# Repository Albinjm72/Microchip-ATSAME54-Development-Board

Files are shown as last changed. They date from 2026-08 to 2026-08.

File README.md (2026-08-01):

<div align="center">

# ATSAME54N20A-AU Development Board

**A custom-designed development board built around the Microchip ATSAME54N20A-AU (ARM Cortex-M4F)**

Designed end-to-end in KiCad — schematic, routing, and silkscreen.

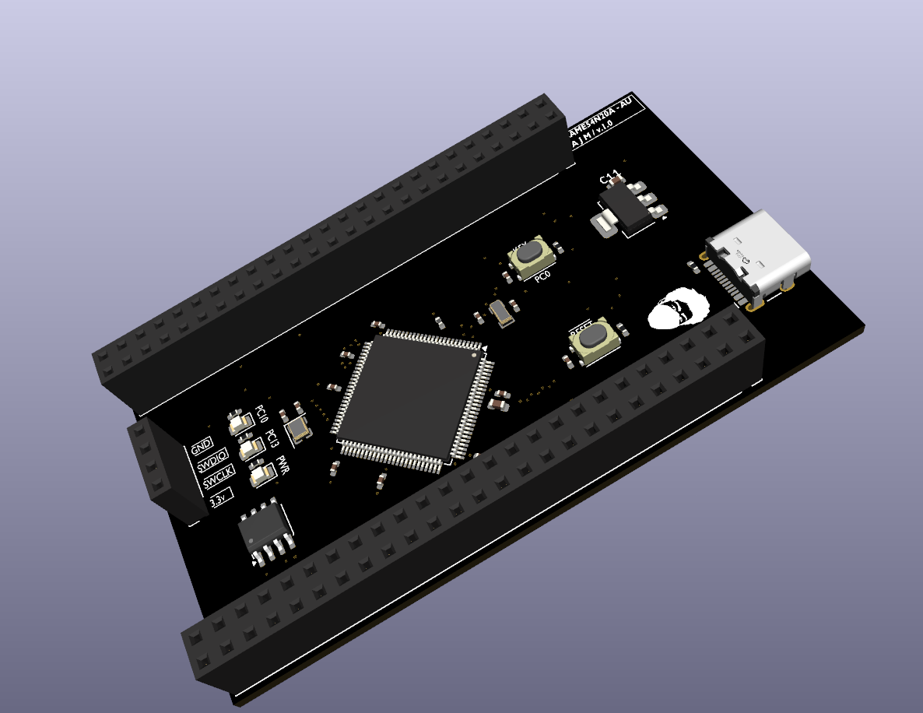
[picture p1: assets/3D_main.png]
Board Render


</div>

---

## Overview

This is a fully custom development board designed from a bare microcontroller datasheet up — power architecture, signal routing, and silkscreen branding all done by hand in KiCad, not adapted from a reference design.

## Features

| Feature | Detail |
|---|---|
| **MCU** | Microchip ATSAME54N20A-AU — ARM Cortex-M4F, 120MHz, 1MB flash, 100-pin TQFP |
| **USB** | USB Type-C connector (power + native USB) |
| **CAN** | Onboard CAN controller/transceiver for real bus communication |
| **Storage** | microSD card slot (SDHC) + external QSPI flash |
| **Debug** | SWD programming/debug header |
| **Indicators** | 1x power LED, 2x user-controllable LEDs |
| **I/O** | Dual 2-row GPIO headers (one on each side) — breadboard-compatible pitch |

## Board layout

- **Left and right edges:** two rows of breakout headers on each side, broken out to standard 2.54mm pitch for direct breadboard use
- **Top section:** power, USB-C, SD card slot, SWD header
- **Center:** ATSAME54N20A-AU (TQFP-100)

## Getting started

1. Clone this repository
2. Open `ATSAME54N20A-AU.kicad_pro` in **KiCad 10** or later
3. Manufacturing-ready files are already generated under `gerber_to_order/` if you just want to order the board as-is

## Programming

Program and debug via the onboard **SWD header** using any ARM-compatible probe (ST-Link, J-Link, Atmel-ICE, or similar), through OpenOCD/GDB or MPLAB X.

## Bill of Materials

Full BOM with reference designators, values, and footprints is in `production/bom.csv`.

## Revision history

See [CHANGELOG.md](CHANGELOG.md) for what changed between board revisions.

## License

Licensed under [CERN-OHL-S v2](LICENSE).

## Status

🔧 **Active development** — first hardware revision fabricated, pending assembly and bring-up testing.

---

<div align="center">
<sub>Built with KiCad · Designed by Albin Jose Mathew</sub>
</div>

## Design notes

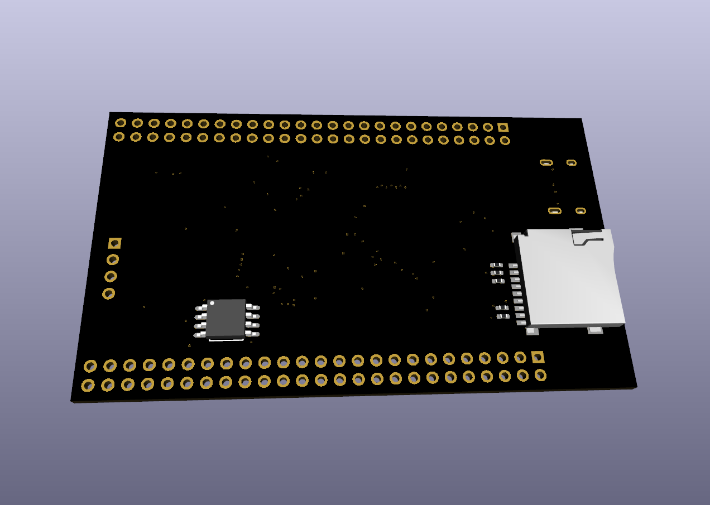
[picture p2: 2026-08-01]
assets/3D_Bottom.png

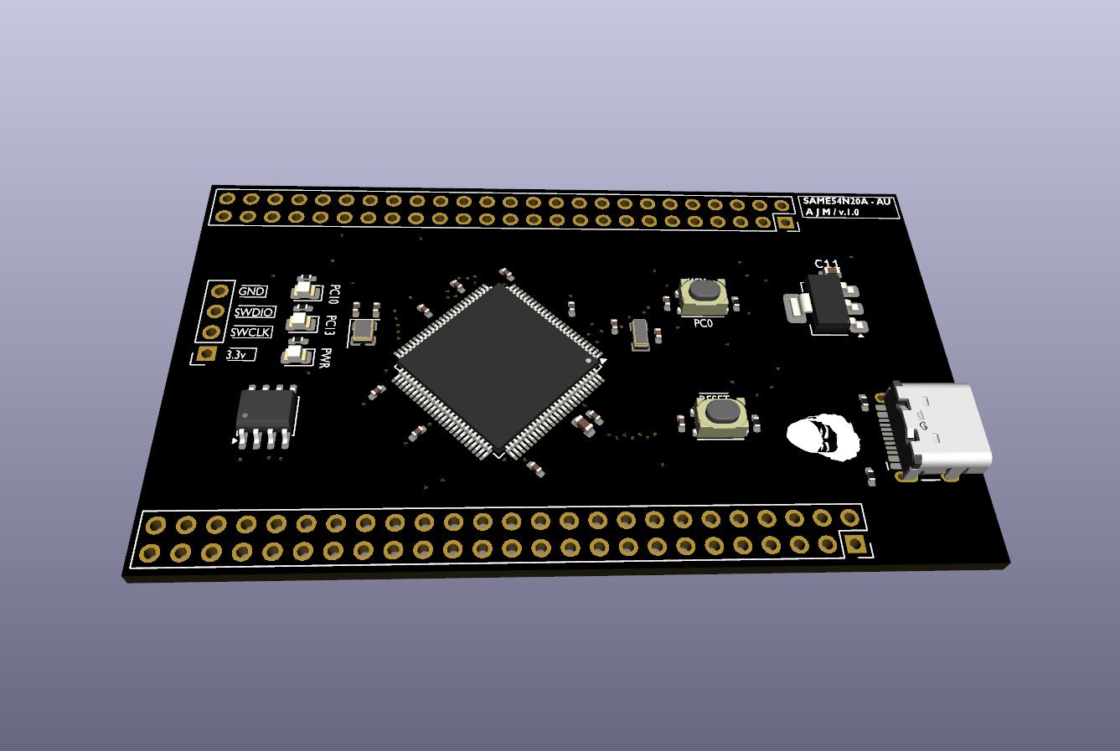
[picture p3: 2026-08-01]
assets/3D_Top_2.png

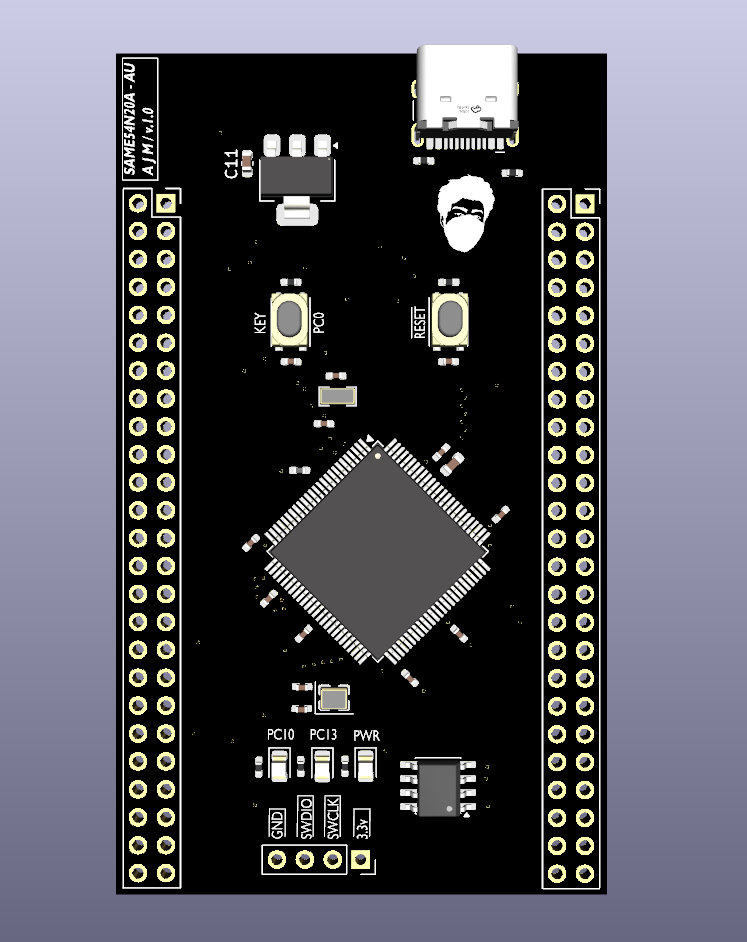
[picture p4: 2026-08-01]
assets/3D_Top_1.png

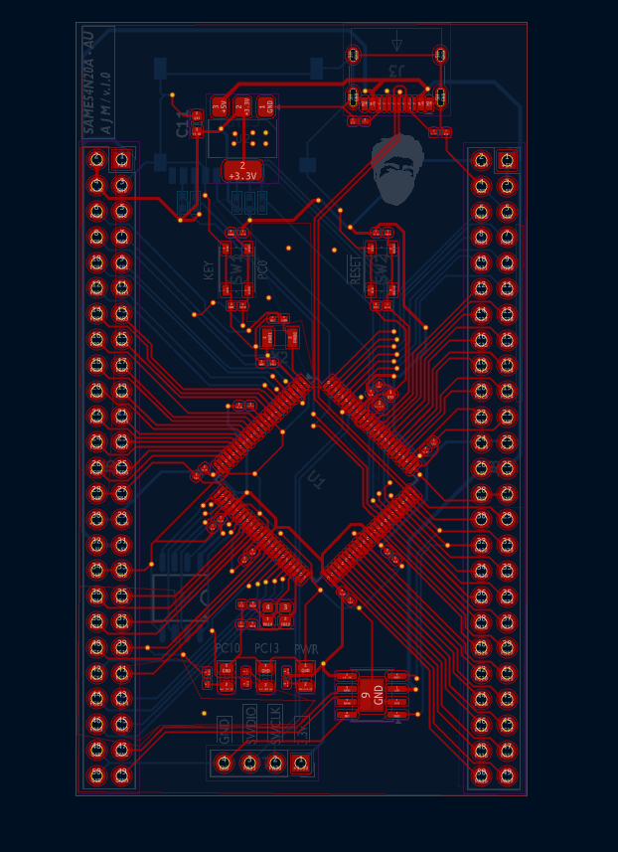
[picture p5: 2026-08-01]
assets/Layout_Top.png

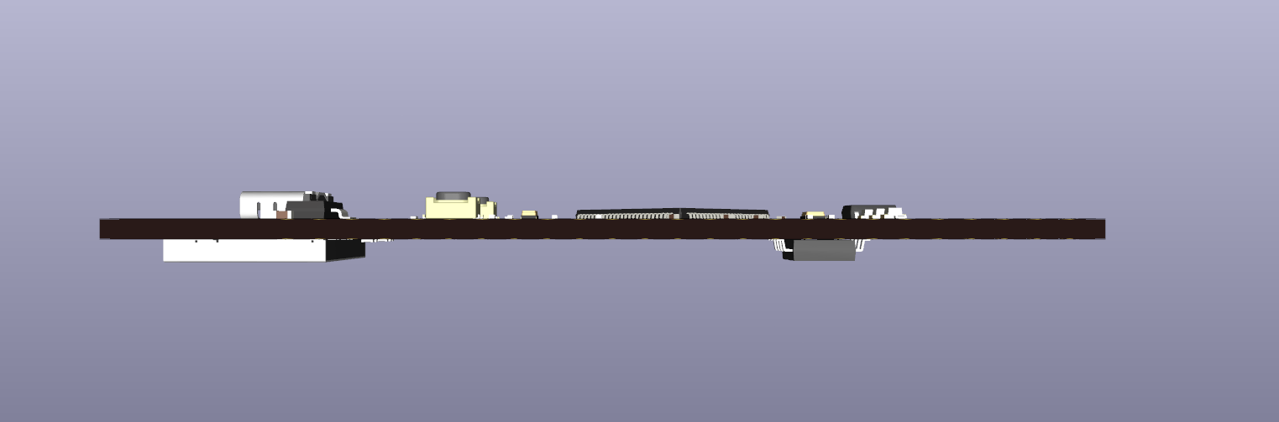
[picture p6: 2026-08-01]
assets/3D_Side_2.png

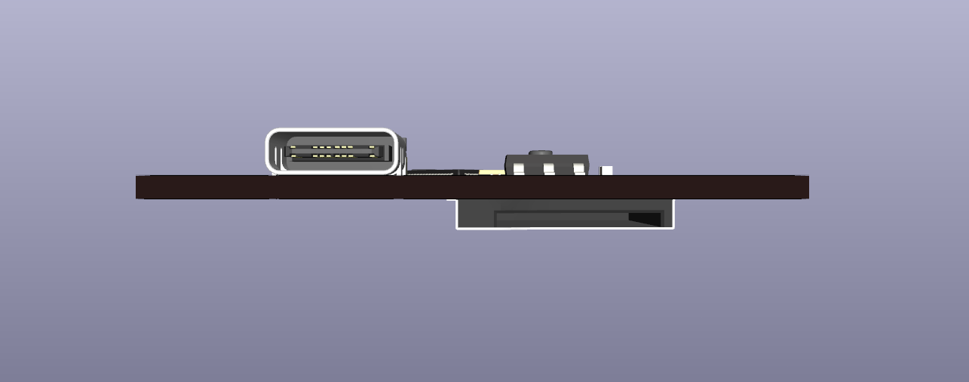
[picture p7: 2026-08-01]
assets/3D_Side_1.png

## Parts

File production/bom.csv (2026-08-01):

Designator | Footprint | Quantity | Value | LCSC Part #
C1, C2, C3, C4, C5, C6, C7, C8, C9 | 0402 | 9 | 100nF
C10 | 0603 | 1 | 1uF
C11 | 0603 | 1 | 10uF
C12, C13 | 0402 | 2 | 12pF
C14, C15 | 0402 | 2 | 15pF
CARD1 | TF-SMD_THD2528-11SD-GF | 1 | THD2528-11SD-GF | C283232
D1 | 0805 | 1 | 0805 GREEN
D2 | 0805 | 1 | 0805 RED
D3 | 0805 | 1 | 0805 ORANGE
FB1 | 0402 | 1 | 600ohm@100MHz
J3 | USB_C_Receptacle_HCTL_HC-TYPE-C-16P-01A | 1 | USB_C_Receptacle_USB2.0_16P
J6, J8 | PinSocket_2x25_P2.54mm_Vertical | 2 | Conn_01x50_MountingPin
J7 | PinSocket_1x04_P2.54mm_Vertical | 1 | Conn_01x04_Pin
R1, R10, R11, R12, R2, R5, R6, R8, R9 | 0402 | 9 | 10k
R3, R4, R7 | 0402 | 3 | 330
SW1, SW2 | SW_Push_1P1T_NO_Vertical_Wuerth_434133025816 | 2 | SW_Push
U1 | TQFP-100_14x14mm_P0.5mm | 1 | ATSAME54N20A-AU
U2 | SOT-223-3_TabPin2 | 1 | TPS7A0533PDBZ
U3 | SOIJ-8_L5.3-W5.3-P1.27-LS7.9-BL | 1 | SST26VF064Bxx-xxxx-MF | C638561
U4 | SOIC-8-1EP_3.9x4.9mm_P1.27mm_EP2.41x3.3mm | 1 | MCP2542FDxMF
Y1 | Crystal_SMD_2520-4Pin_2.5x2.0mm | 1 | Crystal
Y2 | Crystal_SMD_3215-2Pin_3.2x1.5mm | 1 | 32.768kHz

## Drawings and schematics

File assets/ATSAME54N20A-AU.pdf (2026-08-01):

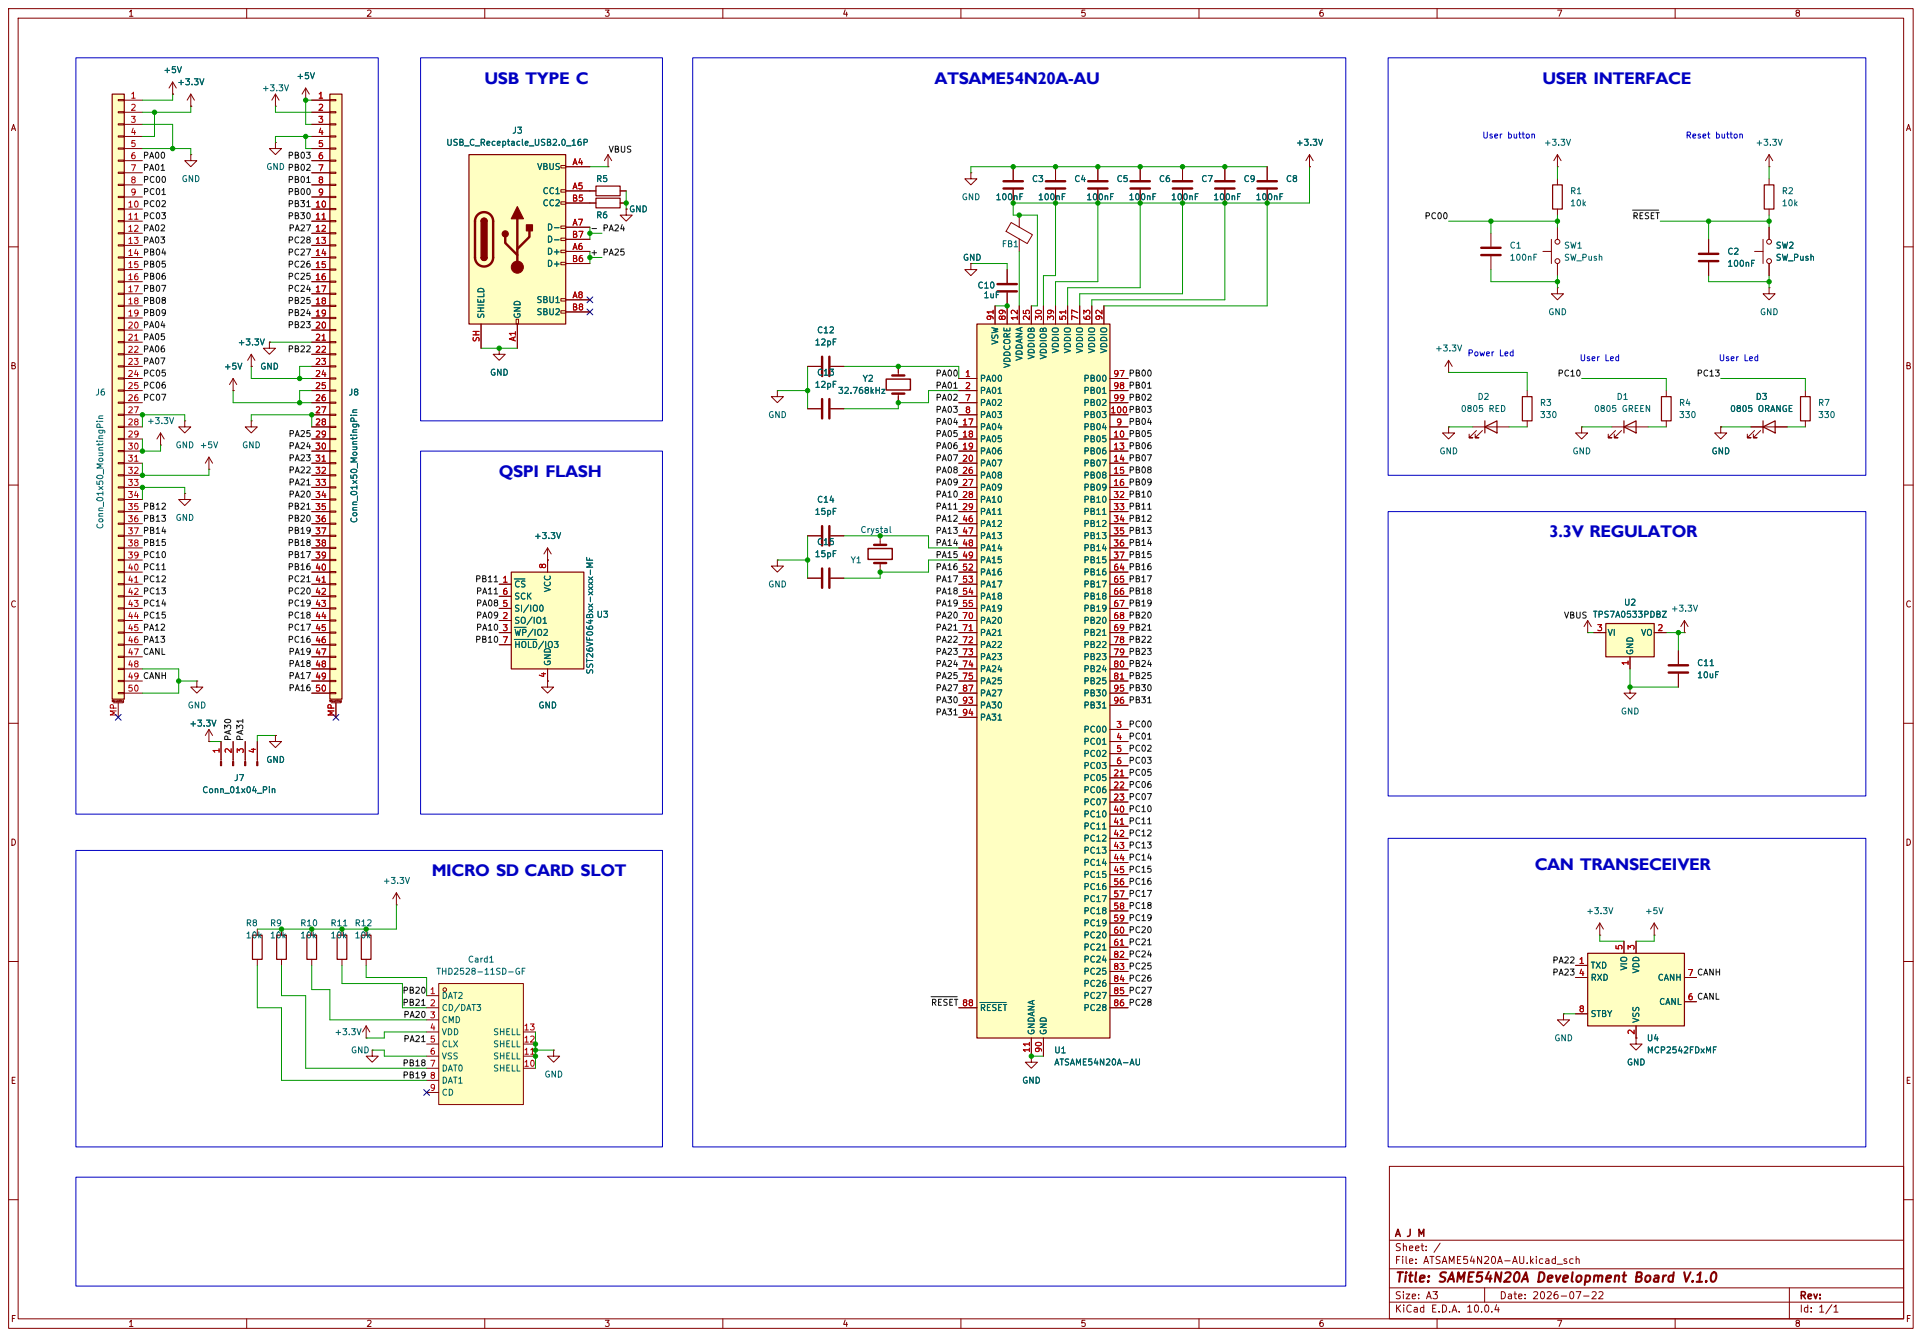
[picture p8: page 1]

User button USB TYPE C

User Led USER INTERFACE
0805 ORANGER2

PB05 PB01 PB02 PB04 MICRO SD CARD SLOT

SHELL 10 SHELL 11 SHELL 12 SHELL 13 Card1

File: ATSAME54N20A-AU.kicad_sch Sheet: /
Id: 1/1 Title: SAME54N20A Development Board V.1.0

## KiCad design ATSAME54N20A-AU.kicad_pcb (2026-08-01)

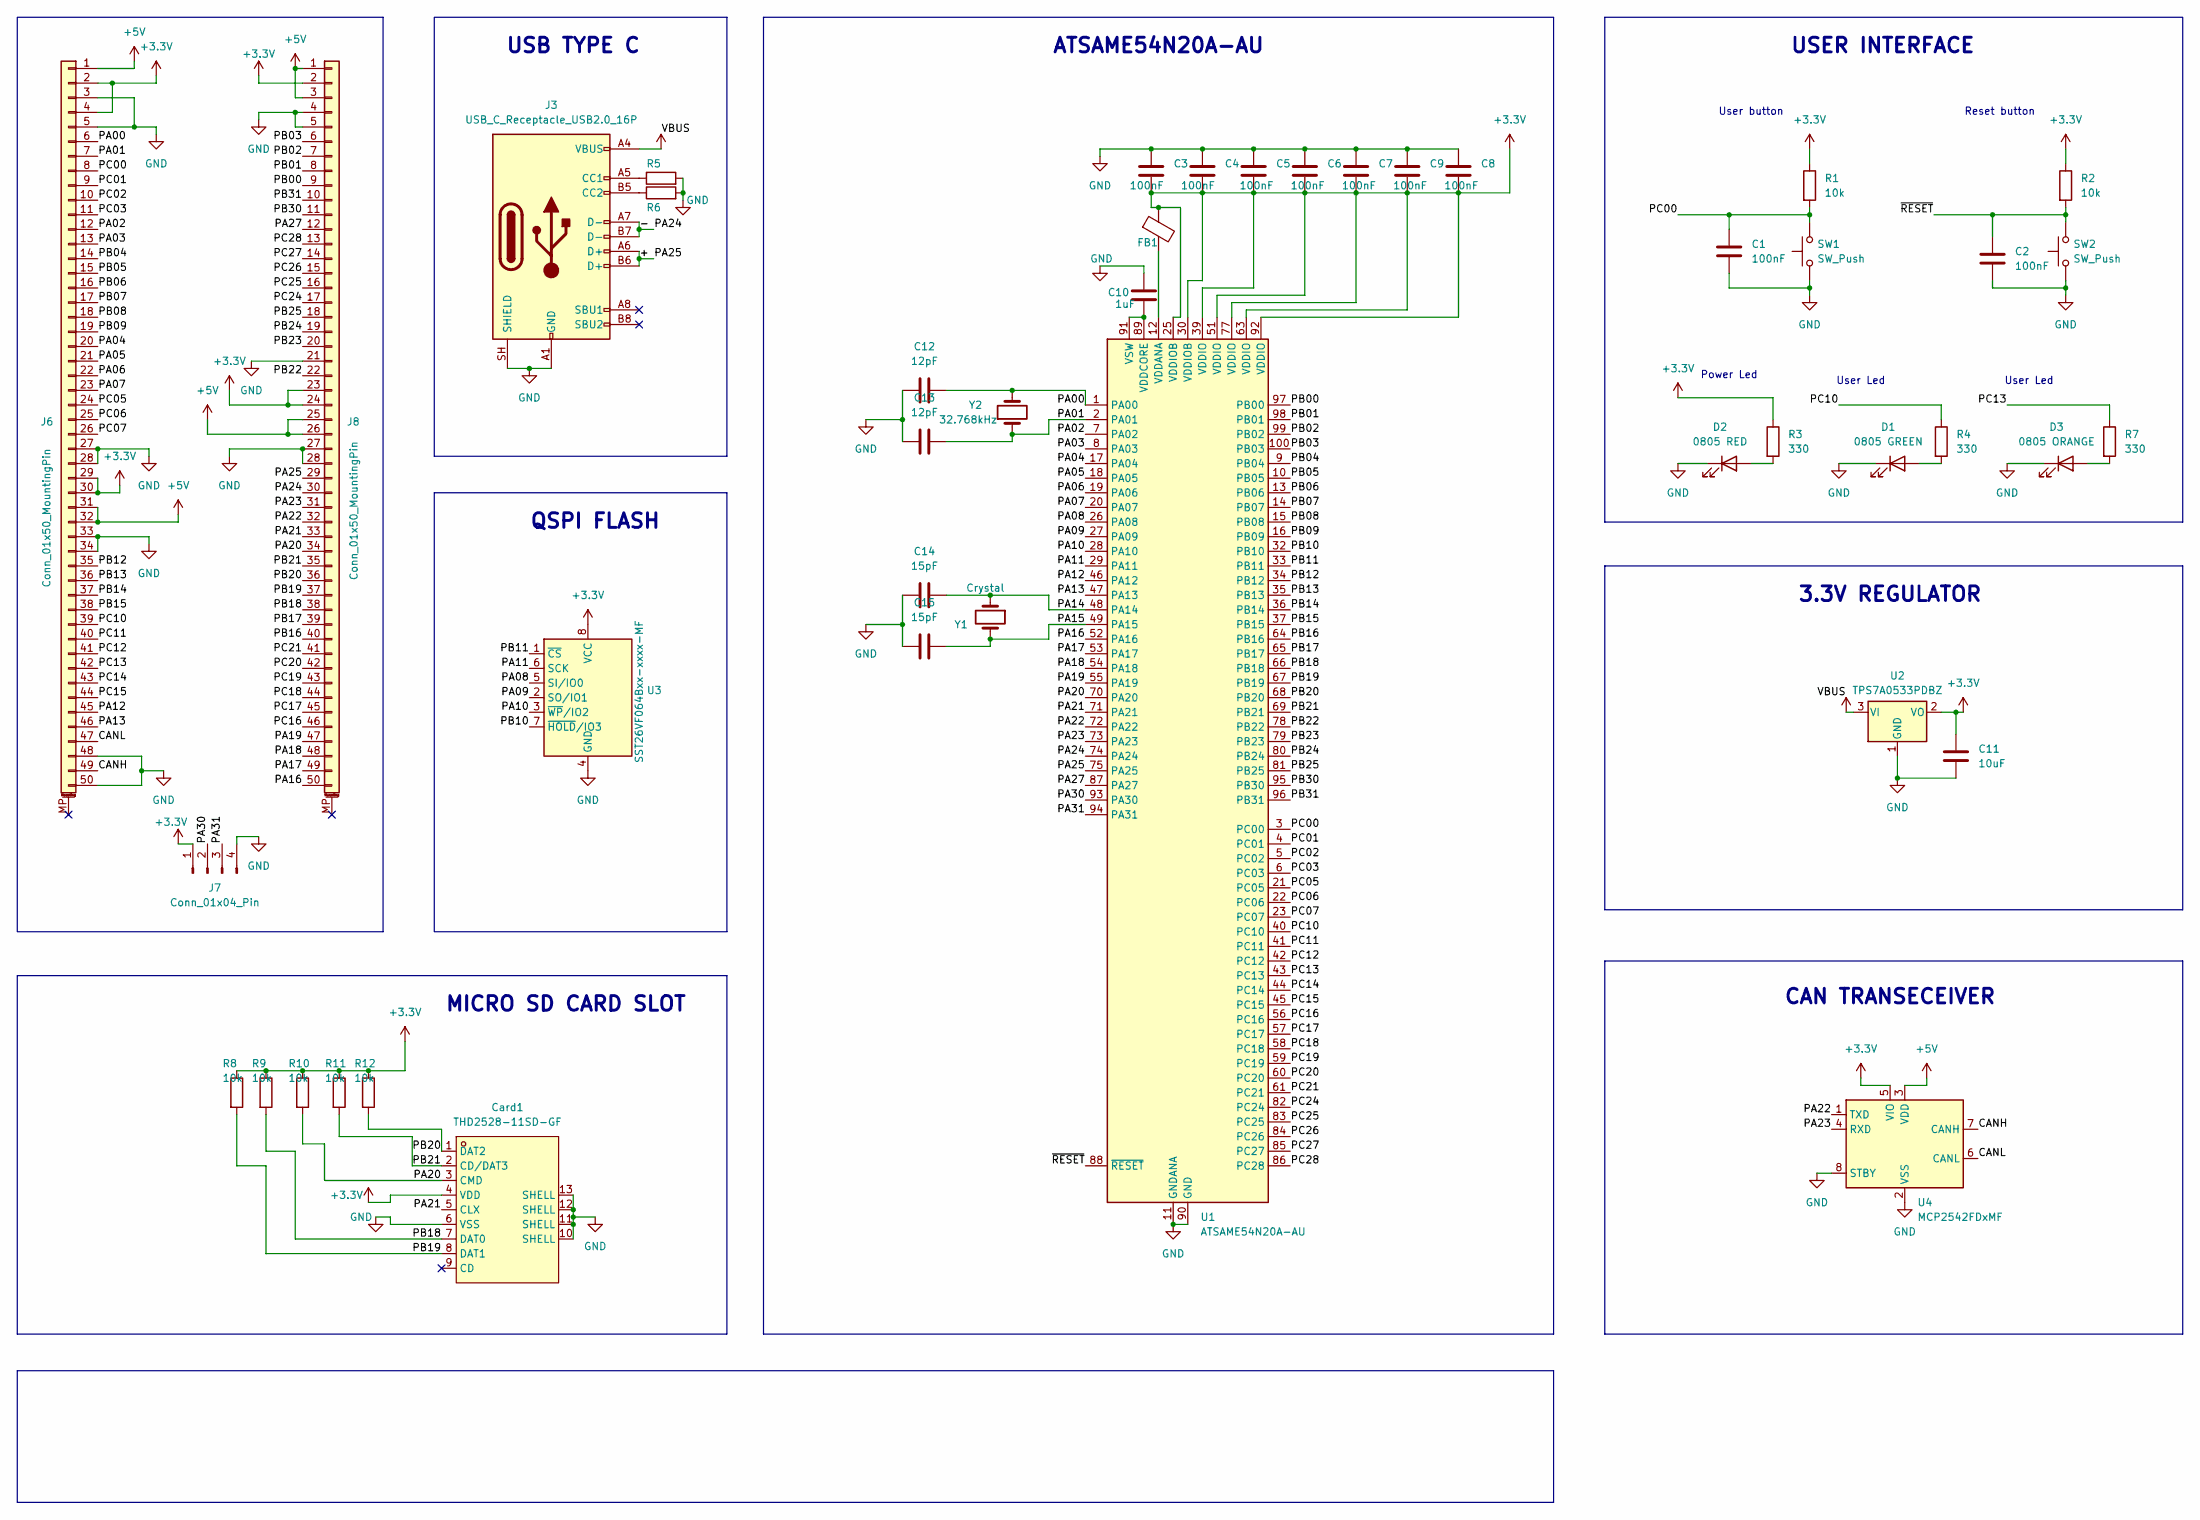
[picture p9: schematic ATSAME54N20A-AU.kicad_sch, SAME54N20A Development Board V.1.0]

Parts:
C1, C2, C3, C4, C5, C6, C7, C8, C9: 100nF; C_0402_1005Metric_Pad0.74x0.62mm_HandSolder
C10: 1uF; C_0603_1608Metric
C11: 10uF; C_0603_1608Metric
C12, C13: 12pF; C_0402_1005Metric_Pad0.74x0.62mm_HandSolder
C14, C15: 15pF; C_0402_1005Metric_Pad0.74x0.62mm_HandSolder
Card1: THD2528-11SD-GF; TF-SMD_THD2528-11SD-GF; MPN THD2528-11SD-GF; LCSC Part C283232
D1: 0805 GREEN; LED_0805_2012Metric
D2: 0805 RED; LED_0805_2012Metric
D3: 0805 ORANGE; LED_0805_2012Metric
FB1: 600ohm@100MHz; L_0402_1005Metric_Pad0.77x0.64mm_HandSolder
J3: USB_C_Receptacle_USB2.0_16P; USB_C_Receptacle_HCTL_HC-TYPE-C-16P-01A
J6, J8: Conn_01x50_MountingPin; PinSocket_2x25_P2.54mm_Vertical
J7: Conn_01x04_Pin; PinSocket_1x04_P2.54mm_Vertical
R1, R2, R5, R6, R8, R9, R10, R11, R12: 10k; R_0402_1005Metric_Pad0.72x0.64mm_HandSolder
R3, R4, R7: 330; R_0402_1005Metric_Pad0.72x0.64mm_HandSolder
SW1, SW2: SW_Push; SW_Push_1P1T_NO_Vertical_Wuerth_434133025816
U1: ATSAME54N20A-AU; TQFP-100_14x14mm_P0.5mm
U2: TPS7A0533PDBZ; SOT-223-3_TabPin2
U3: SST26VF064Bxx-xxxx-MF; SOIJ-8_L5.3-W5.3-P1.27-LS7.9-BL
U4: MCP2542FDxMF; SOIC-8-1EP_3.9x4.9mm_P1.27mm_EP2.41x3.3mm
Y1: Crystal; Crystal_SMD_2520-4Pin_2.5x2.0mm
Y2: 32.768kHz; Crystal_SMD_3215-2Pin_3.2x1.5mm

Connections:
+3.3V: C3.2, C4.2, C5.2, C6.2, C7.2, C8.2, C9.2, C11.1, Card1.4 (VDD), FB1.1, J6.2, J6.4, J6.29, J6.30, J7.1, J8.2, J8.23, J8.24, R1.1, R2.1, R3.1, R8.1, R9.1, R10.1, R11.1, R12.1, U1.25 (VDDIOB), U1.30 (VDDIOB), U1.39 (VDDIO), U1.51 (VDDIO), U1.63 (VDDIO), U1.77 (VDDIO), U1.92 (VDDIO), U2.2 (VO), U3.8 (VCC), U4.5 (VIO)
+5V: J3.A4 (VBUS), J3.A9 (VBUS), J3.B4 (VBUS), J3.B9 (VBUS), J6.1, J6.31, J6.32, J8.1, J8.3, J8.25, J8.26, U2.3 (VI), U4.3 (VDD)
/+: J3.A6 (D+), J3.B6 (D+), J8.29, U1.75 (PA25)
/-: J3.A7 (D-), J3.B7 (D-), J8.30, U1.74 (PA24)
/CANH: J6.49, U4.7 (CANH)
/CANL: J6.47, U4.6 (CANL)
/PA00: C12.2, J6.6, U1.1 (PA00), Y2.2
/PA01: C13.2, J6.7, U1.2 (PA01), Y2.1
/PA02: J6.12, U1.7 (PA02)
/PA03: J6.13, U1.8 (PA03)
/PA04: J6.20, U1.17 (PA04)
/PA05: J6.21, U1.18 (PA05)
/PA06: J6.22, U1.19 (PA06)
/PA07: J6.23, U1.20 (PA07)
/PA08: U1.26 (PA08), U3.5 (SI/IO0)
/PA09: U1.27 (PA09), U3.2 (SO/IO1)
/PA10: U1.28 (PA10), U3.3 (~WP/IO2)
/PA11: U1.29 (PA11), U3.6 (SCK)
/PA12: J6.45, U1.46 (PA12)
/PA13: J6.46, U1.47 (PA13)
/PA14: C14.2, U1.48 (PA14), Y1.1
/PA15: C15.2, U1.49 (PA15), Y1.2
/PA16: J8.50, U1.52 (PA16)
/PA17: J8.49, U1.53 (PA17)
/PA18: J8.48, U1.54 (PA18)
/PA19: J8.47, U1.55 (PA19)
/PA20: Card1.3 (CMD), J8.34, R10.2, U1.70 (PA20)
/PA21: Card1.5 (CLX), J8.33, U1.71 (PA21)
/PA22: J8.32, U1.72 (PA22), U4.1 (TXD)
/PA23: J8.31, U1.73 (PA23), U4.4 (RXD)
/PA27: J8.12, U1.87 (PA27)
/PA30: J7.2, U1.93 (PA30)
/PA31: J7.3, U1.94 (PA31)
/PB00: J8.9, U1.97 (PB00)
/PB01: J8.8, U1.98 (PB01)
/PB02: J8.7, U1.99 (PB02)
/PB03: J8.6, U1.100 (PB03)
/PB04: J6.14, U1.9 (PB04)
/PB05: J6.15, U1.10 (PB05)
/PB06: J6.16, U1.13 (PB06)
/PB07: J6.17, U1.14 (PB07)
/PB08: J6.18, U1.15 (PB08)
/PB09: J6.19, U1.16 (PB09)
/PB10: U1.32 (PB10), U3.7 (~HOLD/IO3)
/PB11: U1.33 (PB11), U3.1 (~CS)
/PB12: J6.35, U1.34 (PB12)
/PB13: J6.36, U1.35 (PB13)
/PB14: J6.37, U1.36 (PB14)
/PB15: J6.38, U1.37 (PB15)
/PB16: J8.40, U1.64 (PB16)
/PB17: J8.39, U1.65 (PB17)
/PB18: Card1.7 (DAT0), J8.38, R9.2, U1.66 (PB18)
/PB19: Card1.8 (DAT1), J8.37, R8.2, U1.67 (PB19)
/PB20: Card1.1 (DAT2), J8.36, R12.2, U1.68 (PB20)
/PB21: Card1.2 (CD/DAT3), J8.35, R11.2, U1.69 (PB21)
/PB22: J8.22, U1.78 (PB22)
/PB23: J8.20, U1.79 (PB23)
/PB24: J8.19, U1.80 (PB24)
/PB25: J8.18, U1.81 (PB25)
/PB30: J8.11, U1.95 (PB30)
/PB31: J8.10, U1.96 (PB31)
/PC00: C1.1, J6.8, R1.2, SW1.2, U1.3 (PC00)
/PC01: J6.9, U1.4 (PC01)
/PC02: J6.10, U1.5 (PC02)
/PC03: J6.11, U1.6 (PC03)
/PC05: J6.24, U1.21 (PC05)
/PC06: J6.25, U1.22 (PC06)
/PC07: J6.26, U1.23 (PC07)
/PC10: J6.39, R4.1, U1.40 (PC10)
/PC11: J6.40, U1.41 (PC11)
/PC12: J6.41, U1.42 (PC12)
/PC13: J6.42, R7.1, U1.43 (PC13)
/PC14: J6.43, U1.44 (PC14)
/PC15: J6.44, U1.45 (PC15)
/PC16: J8.46, U1.56 (PC16)
/PC17: J8.45, U1.57 (PC17)
/PC18: J8.44, U1.58 (PC18)
/PC19: J8.43, U1.59 (PC19)
/PC20: J8.42, U1.60 (PC20)
/PC21: J8.41, U1.61 (PC21)
/PC24: J8.17, U1.82 (PC24)
/PC25: J8.16, U1.83 (PC25)
/PC26: J8.15, U1.84 (PC26)
/PC27: J8.14, U1.85 (PC27)
/PC28: J8.13, U1.86 (PC28)
/~RESET: C2.1, R2.2, SW2.2, U1.88 (~RESET)
GND: C1.2, C2.2, C3.1, C4.1, C5.1, C6.1, C7.1, C8.1, C9.1, C10.1, C11.2, C12.1, C13.1, C14.1, C15.1, Card1.6 (VSS), Card1.10 (SHELL), Card1.11 (SHELL), Card1.12 (SHELL), Card1.13 (SHELL), D1.1 (K), D2.1 (K), D3.1 (K), J3.A1 (GND), J3.A12 (GND), J3.B1 (GND), J3.B12 (GND), J3.SH (SHIELD), J6.3, J6.5, J6.27, J6.28, J6.33, J6.34, J6.48, J6.50, J7.4, J8.4, J8.5, J8.21, J8.27, J8.28, R5.2, R6.2, SW1.1, SW2.1, U1.11 (GNDANA), U1.24 (GND), U1.31 (GND), U1.38 (GND), U1.50 (GND), U1.62 (GND), U1.76 (GND), U1.90 (GND), U2.1 (GND), U3.4 (GND), U4.2 (VSS), U4.8 (STBY), U4.9 (VSS)
unnamed: D1.2 (A), R4.2
unnamed: D2.2 (A), R3.2
unnamed: D3.2 (A), R7.2
unnamed: J3.A5 (CC1), R5.1
unnamed: J3.B5 (CC2), R6.1
unnamed: FB1.2, U1.12 (VDDANA)
unnamed: C10.2, U1.89 (VDDCORE), U1.91 (VSW)

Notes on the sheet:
User Led
USER INTERFACE
USB TYPE C
Power Led
User button
QSPI FLASH
3.3V REGULATOR
MICRO SD CARD SLOT
ATSAME54N20A-AU
CAN TRANSECEIVER
Reset button

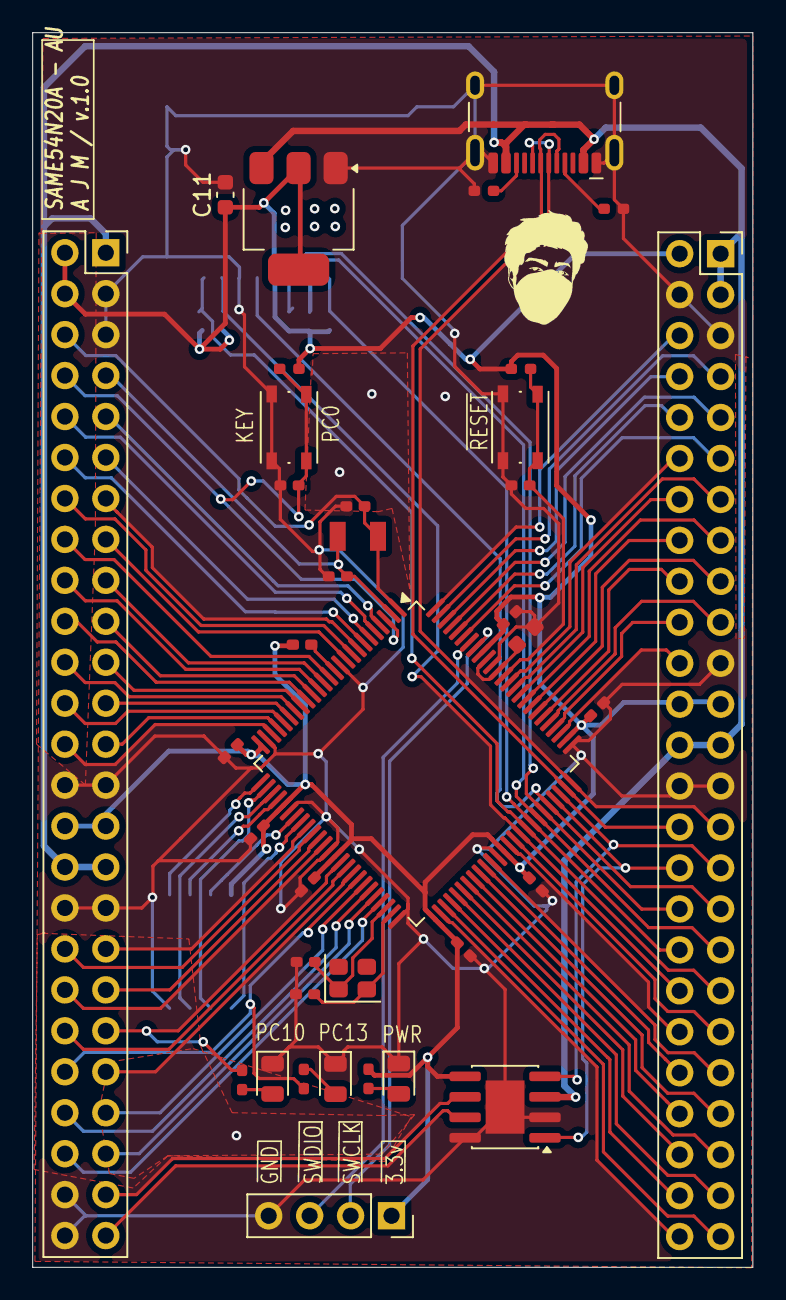
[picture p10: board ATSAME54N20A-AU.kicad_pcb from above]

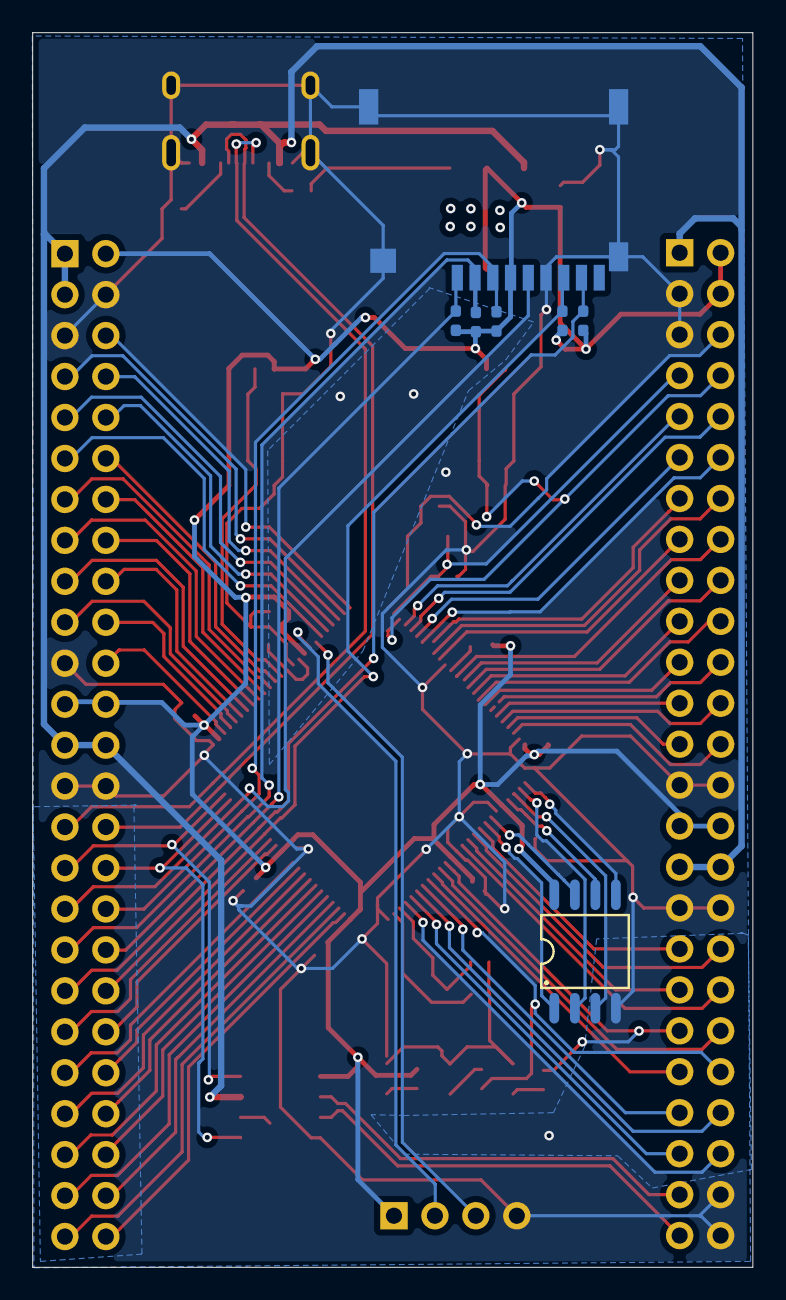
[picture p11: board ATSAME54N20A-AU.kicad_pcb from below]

Board: 2 copper layers, 44.7 x 76.6 mm, 44 parts (7 on the bottom side), 94 nets.

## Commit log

2026-08-01 Initial commit: ATSAME54N20A-AU dev board v1.0
    [ATSAME54N20A-AU.kicad_pcb, ATSAME54N20A-AU.kicad_sch, bom.csv]
2026-08-01 docs: add Circuit Schematic, PCB render and Project images
2026-08-01 Replace license with CERN-OHL-S-2.0
    [designators.csv, positions.csv]
